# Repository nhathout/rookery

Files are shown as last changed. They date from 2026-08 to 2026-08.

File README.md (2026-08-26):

# rookery

**A desk light that tells you what your Claude Code sessions are doing.**

Green while it's working. Red when it wants you. Yellow when it's done. Glance
at the corner of your desk instead of cycling through terminal tabs.

A *rookery* is a penguin colony — which is roughly what a few concurrent agent
sessions feel like, and why one lives on the base.

```
Claude Code ──hooks──▶ localhost:8787 ──▶ daemon ──USB serial──▶ ESP32 ──▶ LEDs
```

No network. No telemetry. No cloud. Your session state never leaves the machine
it's running on.

---

## What it looks like

| LED | State | Meaning |
|---|---|---|
| 🟢 Green, slow breathe | `working` | At least one session is running |
| 🟡 Yellow, steady | `idle` | Sessions open, nothing running |
| 🔴 Red, fast pulse | `needs_you` | A session is waiting on your input |
| 🔵 Blue, very dim | `asleep` | No sessions at all |
| 🟠 Orange, slow blink | `link lost` | The daemon stopped talking — don't trust the light |
| ⚪ White, blink | `ident` | Boot self-test, or you asked it to identify itself |

Sessions are tracked individually and the most urgent one wins, so five
terminals and three worktrees still collapse into one colour.

The enclosure is a **penguin**, 91 × 55 × 117 mm, in two colours: a black
shell and a **white belly that the LEDs light from behind**. The belly is a
swappable panel — a smiley, a chick, a word, or your own — and it's the only
part you ever need to take out. Its glyph is thinned to 0.9 mm so it glows
while the rest of the panel stays opaque.

The eyes are translucent plugs that pick up spill light from inside, so they
glow faintly in whatever colour is currently showing.

---

## Bill of materials

If you own a 3D printer and a parts drawer, you probably have all of this.

| Item | Qty | Notes |
|---|---|---|
| ESP32-S3 dev board | 1 | Classic ESP32, C3 and C6 also supported |
| LEDs — red, green, blue, yellow, orange, white | 1 each | 3 mm or 5 mm through-hole |
| Resistors, 100–330 Ω | 6 | Values vary by colour — see [WIRING.md](hardware/WIRING.md) |
| M3 heat-set inserts | 6 | 4.0 mm OD, 5 mm long |
| M3 × 1/4" screws | 6 | Standard PC case screws — Micro Connectors `SCW-50M3` or any M3 × 6 mm pan head |
| **USB cable that carries data** | 1 | Not a charge-only cable |
| Zip tie, small | 1 | Strain relief on the cable |
| Black filament | ~95 g | Shell and backplate |
| White or natural filament | ~25 g | Nest, eyes, and one belly |
| *Optional:* rubber feet, 11 mm | 4 | Recesses are in the base |

Every screw in the build is the same one: **M3 × 1/4"**, six of them, into six
M3 heat-set inserts. There is nothing else to source.

Only one LED is ever lit at a time, so there's no capacitor, no level shifter
and no external power supply. The whole thing runs off the USB port that's
already carrying the serial data.

---

## Build

### 1. Flash the firmware

```bash
pip install platformio
cd firmware
pio run -e esp32s3 -t upload
pio device monitor              # expect: READY rookery 0.2.0 channels=6
```

On boot the firmware walks all six LEDs in order as a self-test. If one stays
dark, that's a wiring fault — find it now, before anything is soldered.

> **ESP32-S3 users:** a DevKitC-1 has two USB-C sockets. The default build
> routes Serial to the **native USB** port (marked `USB`). If your board has
> only one socket, that's the one. To use the `UART` bridge instead, build
> `esp32s3-uart`.

Other targets: `esp32dev`, `esp32c3`, `esp32c6`, `esp32s3-penguin` (adds the
servo), `esp32s3-neopixel` / `esp32s3-rgb` (alternate LED hardware).

### 2. Install the daemon

```bash
cd host
pip install -e .

rookery ports     # find your board (* marks likely candidates)
rookery probe     # confirm it answers
rookery test      # cycle green → yellow → red → blue
```

If `test` cycles the colours, the hardware is finished. Everything after this
is software.

**Linux:** for serial permissions, either `sudo usermod -aG dialout $USER`
(then log out and back in), or install
[`scripts/99-rookery.rules`](scripts/99-rookery.rules) for a stable
`/dev/rookery` symlink that survives replugging.

### 3. Wire it to Claude Code

```bash
rookery install-hooks
```

Merges the hook entries into `~/.claude/settings.json`, backing up the original
to `settings.json.bak` first. It only ever touches its own entries — your
existing hooks are preserved — and re-running it is idempotent.

Prefer to do it by hand? Paste [`claude/hooks.http.json`](claude/hooks.http.json)
into your settings yourself. To undo: `rookery uninstall-hooks`.

### 4. Run it

```bash
rookery run
```

Open Claude Code in another terminal and ask it something.

Autostart on Linux:

```bash
mkdir -p ~/.config/systemd/user
cp scripts/rookery.service ~/.config/systemd/user/
systemctl --user daemon-reload
systemctl --user enable --now rookery
sudo loginctl enable-linger $USER    # survive logout
```

macOS: [`scripts/com.rookery.daemon.plist`](scripts/com.rookery.daemon.plist).

### 5. Print the enclosure

**The meshes are committed — you don't need to run anything.** The `.3mf`
files in [`hardware/stl/`](hardware/stl/) are pre-arranged plates: open one in
Bambu Studio and every part arrives laid out and correctly oriented.

Five printed parts, in two colours:

| Part | Filament | What it is |
|---|---|---|
| `shell` | **Black** | The body — head, flippers, beak, belly window, eye sockets |
| `backplate` | **Black** | Rear panel; the board and the nest mount on it |
| `nest` | **White** | Holds the six LEDs and reflects their light into the belly |
| `eyes` | **White / natural** | Two plugs on a bridge |
| `belly_*` | **White / natural** | The diffuser. Pick one — this is the swappable bit. |

Plates are grouped by filament colour, so a single-extruder machine never
needs a mid-print swap:

| Plate | Filament | Parts |
|---|---|---|
| `plate1_black.3mf` | Black | `shell` |
| `plate2_black.3mf` | Black | `backplate` |
| `plate3_white.3mf` | White | `nest`, `eyes`, `belly_blank`, `belly_smiley` |
| `plate4_white.3mf` | White | `belly_chick`, `belly_text` |

Everything fits a **Bambu A1 mini** (180 × 180 × 180). If you have a 256 mm
machine, `python3 generate.py --plate 256` re-packs the set onto two plates.

3 walls, 15–20% infill, 0.2 mm layers, and **no supports on any part** —
nothing in the design overhangs past 45°, and `generate.py` measures that
rather than assuming it.

**The belly must be white or natural filament.** Its glyph is thinned to
0.9 mm while the panel around it is 2.6 mm, so light passes through the glyph
and not the frame. A dark filament gives you a dim brown oval. The `nest` is a
reflector, so print that in white too.

To change dimensions, edit the parameters at the top of
[`hardware/generate.py`](hardware/generate.py) and re-run it:

```bash
pip install trimesh manifold3d shapely numpy
cd hardware
python3 generate.py                    # rewrites stl/
python3 generate.py --insert-od 4.2    # if your inserts are fatter
python3 generate.py --led-d 3.0        # 3 mm LEDs instead of 5 mm
python3 generate.py --text "BUSY"      # your own wording
```

Every run checks itself: manifoldness after welding, plate fit, unsupported
overhang area, bridge spans, screw thread engagement, and a boolean
interference test of the assembled parts against each other and against a
solid standing in for the dev board. A bad parameter fails loudly instead of
at the printer.

### 6. Bellies

Four ship ready to print:

| Belly | What it shows |
|---|---|
| `belly_blank` | Plain glow — the whole oval lights up |
| `belly_smiley` | A smiley face — the most legible of the four |
| `belly_chick` | A pixel penguin chick, on a penguin's belly |
| `belly_text` | Reads `AFK`; change it with `--text` |

Swapping one is four screws, all on the back. The whole electrical assembly
stays on the backplate as one piece — nothing gets unsoldered.

If you design your own, keep the lit graphic **small and central**. The six
LEDs sit in a 15 mm circle about 18 mm behind a 48 × 54 mm window, so a
compact centred icon lights evenly while a graphic that reaches the rim falls
off at the edges. The text belly uses a built-in 5 × 7 bitmap font covering
A–Z, 0–9 and a few symbols, auto-scaled to fit.

Full print-and-assemble walkthrough, including the heat-set insert technique
and the order to do things in: [`hardware/stl/README.md`](hardware/stl/README.md).
Circuit and resistor values: [`hardware/WIRING.md`](hardware/WIRING.md).

---

## Usage

```bash
rookery run --brightness 90    # dimmer, for a dark room
rookery run --simulate         # log state changes, no hardware needed
rookery status                 # which sessions does it think are live?
rookery set needs_you          # force a state (stop the daemon first)
rookery print-hooks            # dump the hook JSON to stdout
```

`--simulate` is genuinely useful: you can verify the whole hook pipeline before
the hardware exists.

Six LEDs from a parts drawer will never be balanced. Trim them live over serial
with `GAIN <colour> <0-255>`, then bake the values you settle on into
`build_flags` — `env:esp32s3-tuned` in `platformio.ini` exists for that.
`WAG` triggers the penguin manually.

Full serial reference: [`docs/PROTOCOL.md`](docs/PROTOCOL.md).

---

## Troubleshooting

**Board doesn't appear in `rookery ports`** — 90% of the time it's a
charge-only USB cable. Then it's the wrong socket on an S3 (native vs UART).
Then it's a missing CP210x/CH340 driver on macOS or Windows.

**Light never changes** — run `rookery status` while a session is live. If
sessions are listed, the problem is the serial link; if not, it's the hooks.
Run `/hooks` inside Claude Code to confirm they registered.

**Light stuck on green** — the daemon died. The firmware notices after 30 s and
switches to the orange blink.

**One LED never lights during the boot self-test** — that channel is miswired,
or the LED is in backwards. The long leg is the anode and goes to the resistor.

**Blue or white looks dead or very faint** — expected, not a fault. Their
forward voltage is nearly the full 3.3 V a GPIO can supply, so they only get
about 2 mA where the others get 7. The firmware already compensates with higher
PWM duty; [`hardware/WIRING.md`](hardware/WIRING.md) has two stronger fixes.

**The belly glows brightest in the middle** — six LEDs in a 15 mm circle
lighting a 48 × 54 mm window will always fall off toward the edges. The
reflector cone and the lens boss on the back of the belly are there to fight
that, but the cheapest fix by far is to **sand the dome of each LED flat on
400-grit** until it's frosted. That turns a ~20° beam into a wide scatter and
does more than either of the other two.

**Belly is dim overall** — wrong filament. It needs white or natural PLA.
Print the `nest` in white too; it's a reflector. Also check `BRIGHT` isn't
turned down.

**Eyes barely glow** — expected. They're lit by spill light through a gap in
the crown of the reflector, so they're subtle by design and best seen in a dim
room. Printing them in natural or clear filament rather than white helps a
lot.

**Hook errors in the transcript** — the daemon isn't running. HTTP hooks report
a connection failure as a non-blocking error: visible, harmless, and it won't
interrupt your work. Switch to the command-hook variant if it bothers you; that
one exits 0 silently.

---

## Extending it

Nothing below the hook layer is Claude Code-specific. The daemon accepts any
POST to `/hook` carrying a `hook_event_name` and a `session_id`, so pointing
another tool at it is a matter of mapping that tool's events onto the four
states in [`host/rookery/state.py`](host/rookery/state.py).

The serial protocol is plain text, so you can drive the light from a shell
script, a CI webhook, or a build system without going near the daemon:

```bash
printf 'STATE needs_you\n' > /dev/rookery
```

`LED <colour> <0-255>` addresses any single LED directly if you want to invent
your own signals.

---

## Repository layout

```
firmware/         ESP32 firmware (PlatformIO)
host/rookery/     the daemon: hook endpoint, session registry, serial link
claude/           hook configuration for Claude Code
hardware/
  generate.py     parametric model generator -> STL + per-colour 3MF plates
  stl/            printable meshes, plates, and the assembly guide
  WIRING.md       circuit, resistor values, where the LEDs sit
  MOTOR.md        power budget, and adding a motor
  PRODUCTION.md   what it costs to build, and to sell
scripts/          systemd unit, launchd plist, udev rules
docs/             serial protocol reference
```

---

## Credit

The idea of a physical desk light for agent sessions isn't mine — I saw
[clawlight.dev](https://clawlight.dev), wanted one, and decided building it
would be more fun than buying it.

This is an independent implementation: its own firmware, daemon and enclosure,
six discrete LEDs instead of a diffused RGB beacon, a penguin-shaped
two-colour enclosure with a swappable backlit belly that isn't in their
product at all, and a hook-driven approach rather than session-file
watching. If you'd rather have a finished product in a nice case than a weekend
of soldering, go buy theirs.

Not affiliated with Anthropic, or with Claw Light.

## License

MIT — see [LICENSE](LICENSE).

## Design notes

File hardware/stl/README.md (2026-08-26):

# Printing and assembling the penguin

Everything in this folder is generated by [`../generate.py`](../generate.py)
and committed, so you don't need to run anything to print it.

The enclosure is a penguin, in two colours: a **black shell** and a **white
belly** that the LEDs light up from behind. Assembled it's **91 × 55 × 117 mm**
and stands on your desk.

Five printed parts, six screws, six heat-set inserts. No supports anywhere.

---

## What's in here

| File | Qty | Filament | What it is |
|---|---|---|---|
| `shell.stl` | 1 | **Black** | The body. Head, flippers, beak, belly window, eye sockets. |
| `backplate.stl` | 1 | **Black** | The rear panel. Everything electrical mounts on it. |
| `nest.stl` | 1 | **White** | Holds the six LEDs and reflects their light into the belly. |
| `eyes.stl` | 1 | **White** | Two plugs on a bridge. One part, both eyes. |
| `belly_*.stl` | 1 | **White / natural** | The diffuser. **Pick one** — this is the swappable bit. |

Four bellies ship ready to print:

| Belly | What it shows |
|---|---|
| `belly_blank` | Plain glow. The whole oval lights up evenly. |
| `belly_smiley` | A smiley face — the most legible of the four |
| `belly_chick` | A pixel penguin chick, on a penguin's belly |
| `belly_text` | Reads `AFK`; change it with `--text` |

### The plates

The `.3mf` files are pre-arranged plates. Open one in Bambu Studio and it
arrives laid out and correctly oriented — **don't rotate anything.**

| Plate | Filament | Parts | Rough time |
|---|---|---|---|
| `plate1_black.3mf` | Black | `shell` | ~5 h |
| `plate2_black.3mf` | Black | `backplate` | ~2 h |
| `plate3_white.3mf` | White | `nest`, `eyes`, `belly_blank`, `belly_smiley` | ~3 h |
| `plate4_white.3mf` | White | `belly_chick`, `belly_text` | ~2 h |

Plates are grouped by colour so a single-extruder machine never needs a
mid-print swap. Everything fits a **Bambu A1 mini** (180 × 180 × 180); the
largest part is the shell at 91 × 117 × 52 mm. If you have a 256 mm machine,
`python3 generate.py --plate 256` re-packs the whole set onto two plates.

You only need one belly to build the thing. Print the other three whenever.

### Print settings

| | |
|---|---|
| Layer height | 0.2 mm |
| Walls | 3 |
| Infill | 15% (`shell`, `backplate`), 20% (`nest`, `eyes`, `belly_*`) |
| Supports | **None.** Not on any part. |
| Brim | Not needed — every part has a large flat face on the plate |

Nothing in this design overhangs past 45°. That is checked, not assumed:
`generate.py` measures the downward-facing area of every part in its print
orientation and fails if any of it is unsupported.

> **The belly must be white or natural filament.** Its glyph is thinned to
> 0.9 mm while the panel around it is 2.6 mm, so light passes through the
> glyph and not the frame. A dark filament gives you a dim brown oval.

Printing the `nest` in white matters too — it's a reflector, and its whole
job is bouncing light. Print the `eyes` in natural/clear if you have it;
they pick up spill light from inside and glow faintly.

---

## Bill of materials

| Item | Qty | Notes |
|---|---|---|
| ESP32-S3 dev board | 1 | Classic ESP32, C3 and C6 also supported |
| LEDs — red, green, blue, yellow, orange, white | 1 each | 5 mm through-hole (or 3 mm, see `--led-d`) |
| Resistors, 100–330 Ω | 6 | Values per [`../WIRING.md`](../WIRING.md) |
| **M3 heat-set inserts** | 6 | 4.0 mm OD × 5 mm long |
| **M3 × 1/4" screws** | 6 | Standard PC case screws — e.g. Micro Connectors `SCW-50M3`. M3 × 6 mm pan or button head is the same thing. |
| Hookup wire | — | Stranded, 26–28 AWG |
| **USB cable that carries data** | 1 | Not a charge-only cable |
| Zip tie, small | 1 | Strain relief on the cable |
| *Optional:* rubber feet, 11 mm | 4 | Recesses are in the base |

**One screw type does the whole build.** All six are the same M3 × 1/4".
Four hold the backplate on, two hold the nest to the backplate.

---

## Assembly

### 0. Get the electronics working first

On a breadboard, before anything is glued or soldered short:

```bash
cd firmware && pio run -e esp32s3 -t upload
cd ../host && pip install -e . && rookery test
```

On boot the firmware walks all six LEDs in order. Any LED that stays dark is
a wiring fault, and you want to find it now rather than after it's inside a
penguin. Full circuit in [`../WIRING.md`](../WIRING.md).

### 1. Fit the six heat-set inserts

Every insert in this build goes into a face you can rest an iron on top of,
straight down. Nothing is fitted at an angle or up inside a cavity.

- **Shell — 4 inserts.** Lay the shell face down, open back up. Four round
  bosses sit against the inside wall: two low, two at shoulder height. Their
  pockets face straight up at you.
- **Backplate — 2 inserts.** Lay the backplate flat, features up. The two
  tall pillars either side of centre are the nest posts. Their pockets are
  in the top of each pillar.

Technique: set the iron to about **200 °C** for PLA, sit the insert on the
hole, and let the iron's own weight carry it in. The pockets have a 45°
lead-in chamfer, so a straight start is easy. Pushing hard squeezes molten
plastic up around the flange and leaves the insert proud. Stop when the top
is flush and let it cool before touching it.

The pockets are cut **3.85 mm** across for a **4.0 mm** insert. That 0.15 mm
is deliberate — it's the material the insert melts into and grips. If yours
measure differently, `python3 generate.py --insert-od 4.2` and reprint.

### 2. Load the LEDs into the nest

Push the six LEDs up through the holes in the flat end of the cone, from
underneath, until they seat. Keep the colour order consistent so you can
trace the loom later.

> **Worth doing:** rub the dome of each LED flat on a bit of 400-grit
> sandpaper until it's frosted. A clear 5 mm LED throws a narrow ~20° beam
> and puts a bright spot in the middle of the belly; a sanded one scatters
> across a much wider angle and lights the whole oval. It costs two minutes
> and it is the single biggest improvement you can make to how this looks.

Bend all six cathodes together into a ring underneath and solder — that's
your ground bus. Solder each anode to its resistor, then a wire from each
resistor back toward the board. **Leave the wires long.** You will regret a
tight loom the first time you open it.

Trim the legs reasonably short and lay them outward: there's 3.3 mm between
the back of the LEDs and the tallest thing on the dev board.

### 3. Screw the nest to the backplate

The nest's two ears sit on the backplate's pillars. **2 × M3 × 1/4"**, from
the cone side.

The cone is the optics. Six single-colour LEDs 18 mm behind a 48 × 54 mm
window would otherwise be a bright spot with a dim rim; the cone flares out
to the full width of the window and bounces the spill into the edges.

### 4. Fit the dev board

It drops into the pocket on four posts and clicks under four retention tabs.
Press it down until it seats. It sits **upright, USB connector pointing
down**, so the cable runs down the inside and out the back at desk level.

Solder the LED loom to the board per the channel map in
[`../WIRING.md`](../WIRING.md).

### 5. Thread the cable

Feed the USB cable in through the slot in the bottom of the backplate
**before** plugging it into the board, then zip-tie it to the two posts
either side of the slot. That way a tug on the cable pulls on the enclosure
and not on the board's USB connector.

### 6. Drop the belly into the shell

From behind, through the open back. The belly's rim is a 45° cone and the
shell's window is countersunk to match, so it self-centres and seats flush
with the outside of the shell. It cannot fall out forward.

While you're in there, press the **eyes** in from behind too. They're
tapered — narrow at the front — so they seat from the inside and can't push
through. A dab of glue on the flange if you want to be sure.

### 7. Close it up

Lower the backplate assembly into the shell. The rim on the backplate locates
it, and the nest's cone lands on the back of the belly and presses it home —
that's deliberate, it's what takes the rattle out.

**4 × M3 × 1/4"** through the back into the shell's inserts. Snug, not tight;
you're clamping a printed part.

Rubber feet in the four recesses underneath if you have them.

---

## Swapping the belly

This is the only reason you'll ever need to open it, which is why all the
screws are on the back where nobody looks.

1. Four screws out, lift the backplate assembly off (mind the LED loom).
2. Push the old belly out from behind and drop the new one in.
3. Backplate back on, four screws.

Nothing gets unsoldered. The whole electrical assembly stays on the
backplate as one piece.

### Designing your own

Start from `belly_blank` and keep the lit graphic **small and central**. The
LEDs sit in a 15 mm circle about 18 mm behind the window, so a compact
centred icon lights evenly while a graphic that reaches the rim falls off at
the edges — the cone and the lens boss fight that, but they don't beat
physics.

For text, `python3 generate.py --text "BUSY"` uses a built-in 5 × 7 bitmap
font covering A–Z, 0–9 and a few symbols, auto-scaled to fit. Four
characters or fewer light most evenly.

If you'd rather model your own from scratch, the part that matters is the
rim: a 45° cone running from a 48 × 54 mm oval at the front face out to
59 × 65 mm over 5.6 mm of depth. Everything behind that is yours.

---

## How the belly is built, and why

Front face to back:

```
   0.0 - 2.6 mm    window plate, 45-degree rim -> wedges into the shell
   2.6 - 5.6 mm    the rim carries on at 45 degrees into the flange
   5.6 - 7.6 mm    flange, straight. The nest presses on this.
```

The middle is pocketed out from the back, which leaves a 2.6 mm window with
a faceted conical boss at its centre. **The boss is the point.** It puts
extra material exactly where the LED beam is strongest and tapers away to
nothing at the edges, so the thing you see is an even glow instead of a hot
spot. The glyph is then thinned from the back to a uniform 0.9 mm floor, so
it reads bright against the field.

The visible face prints against the build plate — best surface finish, and
the thin glow floor is laid down first with no bridging at all.

---

## Regenerating

`stl/` is committed, so you can print without running anything. To change
dimensions:

```bash
pip install trimesh manifold3d shapely numpy
cd hardware
python3 generate.py                    # rewrites stl/
python3 generate.py --insert-od 4.2    # if your inserts are fatter
python3 generate.py --led-d 3.0        # 3 mm LEDs instead of 5 mm
python3 generate.py --belly-clear 0.35 # if the belly is tight
python3 generate.py --text "BUSY"      # your own wording
python3 generate.py --plate 256        # A1 / P1 / X1: two plates instead of four
python3 generate.py --leds ring        # one WS2812B ring instead of six LEDs
```

`--leds ring` reshapes the nest to seat a 12-LED WS2812B ring instead of six
through-hole LEDs: three wires instead of thirteen, and no per-unit colour
trimming. The firmware already has that backend
(`pio run -e esp32s3-neopixel`). Measure your ring and pass `--ring-od` /
`--ring-id` — 12-LED rings are commonly 37 mm across but not universally. The
recess locates the ring; hot glue or foam tape holds it. It's the change to
make if you're building more than one of these — see
[`../PRODUCTION.md`](../PRODUCTION.md).

Every run checks itself and exits non-zero if anything is wrong:

- every part is manifold **after welding at the precision the file is
  written at** — a mesh that only holds together at full float precision
  will fail in someone else's slicer
- every part fits the plate
- no part has unsupported downward-facing area
- the shell's front skin bridges the cavity: the widest span is measured
- the screw arithmetic — thread engagement and clearance past the tip
- the assembled parts are boolean-intersected against each other, and
  against a solid standing in for the dev board, so a clash is a failure
  rather than a surprise at the bench

The two numbers you're most likely to need to change are `INSERT_OD`
(measure your inserts) and `BOARD_L` / `BOARD_W` (measure your board). Both
are at the top of `generate.py`.

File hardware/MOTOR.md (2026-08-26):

# Power budget & adding a motor

> **The shipped enclosure has no servo mount.** The current design is
> deliberately static — shell, backplate, nest, eyes, belly. This document
> stays because the power arithmetic matters for any expansion, and because
> the firmware still carries optional servo support if you want to add a
> moving part of your own.

## Short answer

**No regulator, no external supply.** The light itself draws almost nothing,
and even one micro servo doing brief moves fits inside a USB port's budget with
room to spare. You need one capacitor and one rule about which pin to tap.

The rule: **take servo power from the `5V` / `VIN` pin, never from `3V3`.**

## The budget

A USB 2.0 port gives you **500 mA at 5 V** after enumeration (USB 3.0 gives
900 mA). Most desktop ports will quietly supply more, but 500 mA is the number
to design against.

| Draw | Current |
|---|---|
| ESP32 dev board (WiFi never initialised) | ~50–70 mA |
| USB-UART chip + power LED | ~15–25 mA |
| Status LEDs (one lit at a time, ≤63% duty) | ≤7 mA |
| SG90 servo, moving under light load | ~150–250 mA |
| **Total during a wag** | **~300 mA** ✅ |
| SG90 servo, **stalled** | ~650–750 mA |
| **Total if it stalls** | **~800 mA** ❌ |

So the whole design hinges on one thing: **never let the servo stall.** A
stalled servo will trip your PC's port current limit, and Windows in particular
will disable the port and pop a "USB device drew too much power" notification.

Two defences, both already in the firmware:

- Travel is limited to `SERVO_REST ± SERVO_SWING` (90° ± 28°). Set these so the
  penguin never drives into a hard stop.
- The servo is **detached** 700 ms after a move finishes. A servo that's still
  being commanded holds torque, hunts, and buzzes audibly on a quiet desk.
  Released, an SG90 draws essentially nothing.

## Why not the 3V3 pin

The `3V3` pin comes off the board's onboard linear regulator (usually an
AMS1117). Three problems:

1. A servo wants 5 V. At 3.3 V it's weak and jittery.
2. The regulator is linear, so every milliamp the servo pulls burns
   `(5 − 3.3) × I` watts as heat in a tiny SOT-223 package.
3. Servo inrush yanks the rail down. The ESP32's brownout detector trips
   around 2.6 V on the 3.3 V rail and **resets the chip**.

That third one is the single most common failure in projects like this. The
symptom is a board that reboots every time the motor moves.

## The capacitor

```
  5V (VIN) ──┬──────────────── servo red
             │
          ╔══╧══╗
          ║ 470µF║  electrolytic, 6.3 V or higher
          ╚══╤══╝   stripe = negative = GND side
             │
  GND ───────┴──────────────── servo brown/black
```

470–1000 µF across the servo's supply, physically **close to the servo**, not
next to the ESP32. It absorbs the inrush spike locally so the dip never reaches
the regulator. This is a $0.20 part that prevents the most annoying failure mode
in the build. Fit it.

## Wiring

```
  ESP32                          SG90 servo
  ─────                          ──────────
  5V / VIN ──┬───────────────── red     (power)
          [470µF]
  GND ───────┴───────────────── brown   (ground)

  GPIO17 ───────────────────── orange  (signal)   [S3; GPIO14 on classic]
```

3.3 V PWM into an SG90 works fine — no level shifter needed. If your servo's
wires are a different colour scheme, the order at the connector is almost always
**ground, power, signal** with ground on the outside edge.

Build with the servo enabled:

```bash
pio run -e esp32s3-penguin -t upload      # or esp32dev-penguin
```

That env adds `-DENABLE_SERVO` and pulls in the `ESP32Servo` library.

> **Board note:** the servo needs an **ESP32-S3 or a classic ESP32**. The S3
> has 8 LEDC channels — six LEDs plus one servo is seven, which fits. The C3
> and C6 have exactly six, and the LEDs use all of them.

**If the servo jitters or the LEDs flicker when it moves**, the LEDC peripheral
is being asked to serve two very different clock configurations (the LEDs run
at ~1 kHz / 8-bit, the servo at 50 Hz / 16-bit). The S3's four LEDC timers are
enough for both, but if your core version allocates them awkwardly, moving one
LED to a different GPIO or dropping `analogWriteFrequency` usually settles it.

## Calibration

Assemble loosely first, then in a serial monitor:

```
WAG                 # run the full attention wiggle
LED white 255       # (unrelated, but handy for checking the loom)
```

Adjust in `platformio.ini` and reflash:

- `SERVO_REST` — the neutral angle. Start at 90 and adjust.
- `SERVO_SWING` — how far it turns each way. **Reduce this if the servo grinds
  or buzzes at the extremes** — that's it hitting a mechanical stop, which is
  the stall condition you're trying to avoid.
- `SERVO_STEP_MS` — pace of the wiggle. Higher is calmer.

Get the horn position roughly right *mechanically* before fine-tuning in
software: pull the horn off the spline, centre the servo with `WAG`, and press
the horn back on pointing where you want.

You'll need to make room for it yourself — add a pocket to `build_backplate()`
in `generate.py`, or mount the servo outside the shell. There is room: the
cavity is 46 mm deep and the dev board only uses the bottom 13 mm of it. The
interference check in `generate.py` will tell you straight away if whatever
you add collides with the nest, the belly, or the board.

## What the firmware does with a servo

If you build with `-DENABLE_SERVO`, the servo wags on the **transition into
`needs_you`**, then settles. It deliberately does *not* react to `working` or
`idle` — a desk ornament that moves constantly stops being charming after about
an hour. `WAG` triggers it manually over serial.

The firmware only reacts to the state *change*, not the state value, because
the daemon re-sends the current state every 8 seconds as a heartbeat. Wagging
on the value would mean wagging forever.

## If you'd rather use a different motor

### DC motor

You cannot drive a motor from a GPIO pin. The absolute maximum is 40 mA and the
recommended continuous figure is 12 mA; a motor will pull ten to fifty times
that and take the pin (or the chip) with it.

```
  GPIO ──[ 1kΩ ]── gate/base ┐
                             │  logic-level N-MOSFET (IRLZ44N, 2N7000)
                             │  or NPN (2N2222) for small motors
              source/emitter ┴── GND

  5V ──┬──── motor ──┬── drain/collector
       │             │
       └──|◀── 1N4001 flyback diode, cathode (stripe) to 5V
```

The flyback diode is not optional. Collapsing the motor's magnetic field
generates a reverse spike that will destroy the transistor without it.

Budget-wise: a small hobby DC motor stalls at 0.5–1 A, which blows past your
USB allowance. Fine for brief pulses, not for continuous running.

### 28BYJ-48 stepper + ULN2003

Draws roughly **240 mA continuously while energised** — it fits in the budget,
but it holds that current even when stopped, gets warm, and wastes power. Drive
all four ULN2003 inputs LOW between moves to de-energise it. Uses four GPIOs.

### When you genuinely need external power

More than one servo, any continuous-duty motor, or anything above ~300 mA.

Then: a 5 V 2 A USB wall adapter powering the motor directly, with **grounds
tied together** between the adapter and the ESP32. Keep the ESP32 on the PC's
USB cable for data. Don't feed external 5 V into the board's `5V` pin while
USB is also connected unless you're sure your board has proper diode isolation
— it usually does, but "usually" isn't a thing to bet a motherboard on.

For this project, none of that applies. One servo, one USB cable, one
capacitor.

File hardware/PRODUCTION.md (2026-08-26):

# What it costs to build, and what it would take to sell

This is a parts-drawer project. It is also, with a few changes, a product.
This document is the arithmetic for both, and the honest version of what
stands between them.

Prices are indicative — check them, they move. Everything below assumes PLA,
one Bambu A1 mini, and hand assembly.

---

## Cost of one unit

| Item | Qty | 1-off | @100 |
|---|---|---|---|
| ESP32-S3 DevKitC-1 | 1 | $9.00 | $5.50 |
| LEDs, 5 mm, six colours | 6 | $0.40 | $0.15 |
| Resistors | 6 | $0.06 | $0.02 |
| M3 heat-set inserts | 6 | $0.36 | $0.12 |
| M3 × 1/4" screws | 6 | $0.12 | $0.04 |
| Hookup wire, zip tie | — | $0.25 | $0.10 |
| Rubber feet | 4 | $0.20 | $0.08 |
| USB-A/C data cable, 1 m | 1 | $2.50 | $1.10 |
| Filament — 95 g black | — | $1.90 | $1.60 |
| Filament — 25 g white | — | $0.50 | $0.42 |
| Box, insert, printed card | — | — | $2.20 |
| **Materials** | | **$15.29** | **$11.33** |

**Machine time.** About 12 hours across four plates, or roughly one unit per
A1 mini per day allowing for plate changes. That is not labour, but it is
capital and floor space: **one printer supports about 20 units a month.** Any
real volume means more printers, and printers are the cheapest thing on this
list to add.

**Labour**, which is where this actually gets expensive:

| Step | Time |
|---|---|
| Six heat-set inserts | 3 min |
| Sand six LEDs, load the nest | 4 min |
| Solder the ground bus and six resistors | 14 min |
| Solder seven wires to the board | 8 min |
| Fit board, belly, eyes, close up | 6 min |
| Flash, run `rookery test`, pack | 7 min |
| **Total** | **~42 min** |

At $25/hour that is **$17.50 a unit**, more than the materials. Add a
plausible 8% for scrap and rework and one unit lands at roughly **$30 all-in
at 100 units**.

At a 3× multiple over landed cost — which is thin for hardware once you carry
returns, support and a warranty — that is a **$89 product**. It is not a $39
product, and pretending otherwise is how hardware projects lose money
politely.

---

## The one change that matters

**Thirty of those forty-two minutes are the LED loom.** Six LEDs, six
resistors, a hand-twisted ground bus and thirteen solder joints, done by a
person, every single time. It is also where every unit-to-unit inconsistency
comes from: six LEDs from a parts drawer are never balanced, which is exactly
why `GAIN` exists.

Two ways out, in increasing order of commitment:

### 1. A WS2812B ring — the cheap fix

The firmware already supports this. `-DLED_BACKEND_NEOPIXEL` is in
`platformio.ini` today, as `env:esp32s3-neopixel`.

A 12-LED WS2812B ring module is about $1.50 and has **three wires**. No
resistors, no ground bus, no per-colour trim, no thirteen joints. Assembly
drops from 42 minutes to roughly **15**, and every unit comes out the same
colour as every other unit because the colour is now a number in firmware
rather than a property of whichever LEDs were in the bag.

| | Discrete | WS2812B ring |
|---|---|---|
| Parts | 12 | 1 |
| Solder joints | 13 | 3 |
| Assembly | 42 min | ~15 min |
| Labour @ $25/h | $17.50 | $6.25 |
| BOM change | — | +$1.35, −$0.17 |
| Colour consistency | trim each unit | identical |

That is **$10 a unit** for a $1.35 part, and it pays back on the first one.

The nest needs a ring seat instead of six bores:

```bash
python3 generate.py --leds ring --ring-od 37 --ring-id 23
```

Measure your ring — 12-LED rings are commonly 37 mm across but not
universally. The generator checks the seat against the reflector cone and the
board and fails if it doesn't fit.

The one thing you give up is the constraint that made this design what it is:
one colour at a time, at a few milliamps, off a USB port with no capacitor.
Twelve WS2812Bs at full white are 700 mA. Cap the brightness in firmware and
that is a non-issue, but it is a real change to the power story — see
[MOTOR.md](MOTOR.md).

### 2. A carrier PCB — the right fix at volume

A 40 × 40 mm two-layer board carrying six LEDs, six resistors and one header,
assembled by the fab: roughly $1.50 in boards plus $2–3 in assembly at 50
units, with a one-off setup of about $30–60. Snaps onto the nest's two screw
posts, one connector to the dev board.

It keeps the discrete-LED design exactly as it is — the low current, the one
lit at a time, the honest little indicator — and removes the same 25 minutes.
It costs more per unit than the ring and pays back somewhere around **15–25
units**, so it is the answer if you have decided the six discrete LEDs are the
product rather than an implementation detail.

Beyond a few hundred units, the dev board is the next thing to go: an ESP32-S3
module soldered onto that same PCB removes $3–4 and another connector, at the
cost of needing to care about USB, regulation and certification yourself.

---

## What ships in the box

- Assembled penguin, one belly fitted
- The other three bellies, loose — they are the demo, and they cost 40 g of
  filament and no labour
- USB data cable
- Four rubber feet
- A card with the one-line install and a link

The bellies matter more than they look like they do. They are the thing
someone shows a colleague, they cost almost nothing, and they turn "a light"
into "a light that's mine".

---

## Before you sell one

Not optional, roughly in order of how much they will hurt if skipped:

**The cable.** Half the support load on a project like this is someone using
a charge-only USB cable. Ship a known-good data cable in the box and the
problem disappears. It is the highest-value $1.10 on the BOM.

**Flash and test every unit.** `rookery test` cycles all six colours in about
ten seconds. It catches a cold joint, a backwards LED and a dead channel
before the box is sealed, which is the only place catching them is cheap.

**Regulatory.** In the US, a USB-powered device with no intentional radiator
is subject to FCC Part 15 Subpart B as an unintentional radiator; if you sell
into the EU you need CE/UKCA marking and a declaration of conformity. This is
survivable — a compliance lab will test a unit for a four-figure sum — but it
is a real cost that arrives before revenue, and it is much worse if the
firmware ever brings up WiFi. **Keep the radio off.** The current firmware
never initialises it, and that is worth defending as a design decision rather
than an accident.

**Say what it is.** This talks to Claude Code over local hooks and is not
affiliated with Anthropic. Do not imply otherwise on the box, the listing or
the site. Trademark trouble is cheap to avoid and expensive to fix.

**Firmware version in the greeting.** It is already there — `READY rookery
0.2.0 channels=6` — and it is what makes a support conversation take two
minutes instead of twenty. Bump it on every change that ships.

**Print consistency.** Colour lots vary, and the belly is a diffuser: a
"white" from a different batch changes how the finished thing looks. Buy the
white in quantity from one lot and keep a printed reference belly to compare
against.

---

## What this is worth as a product

Honestly: the enclosure is the product. The firmware and daemon are a
weekend; the thing that makes someone want one is that it is a penguin whose
belly glows, that it comes with four faces, and that swapping one takes four
screws and no soldering.

Which is also the risk. Anyone can print the enclosure — the meshes are MIT
and committed. What is actually being sold is *not having to*: the print
time, the 42 minutes of soldering, the sourcing, the tested unit, the cable
that works. Price it as assembly and support, not as a design people cannot
get, because they can.

The margin is in the assembly time. That is why the ring is the first change
to make, and why the honest answer to "can this be profitable" is: yes, at
around $89, once the LED loom stops being something a person does with their
hands.

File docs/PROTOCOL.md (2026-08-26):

# Serial protocol

115200 baud, 8N1, newline-terminated ASCII. Deliberately human-readable so you
can drive the light from a serial monitor, a shell script, or anything else —
the daemon has no privileged access.

## Host → device

| Command | Effect | Reply |
|---|---|---|
| `PING` | Liveness / identification probe | `PONG rookery 0.2.0` |
| `STATE working` | Green LED, slow breathe | `OK state working` |
| `STATE idle` | Yellow LED, steady dim | `OK state idle` |
| `STATE needs_you` | Red LED, fast pulse | `OK state needs_you` |
| `STATE asleep` | Blue LED, very dim | `OK state asleep` |
| `LED <colour> <0-255>` | Drive one LED directly | `OK led <colour>` |
| `GAIN <colour> <0-255>` | Per-channel brightness trim | `OK gain <colour> <n>` |
| `BRIGHT <0-255>` | Master brightness scale | `OK bright <n>` |
| `WAG` | Run the penguin's attention wiggle | `OK wag` |
| `IDENT` | Blink white for 2 s | `OK ident` |
| `OFF` | Same as `STATE asleep` | `OK off` |

Valid colours: `red`, `green`, `blue`, `yellow`, `orange`, `white` (or the
bare index `0`–`5`).

`GAIN` is how you balance six mismatched LEDs without reflashing. It's a
runtime trim only — set it, find values you like, then move them into
`build_flags`.

`WAG` replies `OK wag ignored` on firmware built without `-DENABLE_SERVO`, so
it's always safe to send. The penguin also wags on its own, but only on the
*transition* into `needs_you` — the daemon re-sends the current state every
8 seconds as a heartbeat, so reacting to the value rather than the change
would make it wag forever.

Unknown commands return `ERR unknown`. Malformed arguments return `ERR <cmd>`.

## Device → host

On boot: `READY rookery 0.2.0 channels=6`

Before that banner the firmware walks all six LEDs in sequence as a self-test.

Nothing else is emitted unsolicited. The daemon drains and debug-logs whatever
arrives, so extra chatter is harmless if you add your own.

## Link watchdog

If the device receives nothing for `LINK_TIMEOUT_MS` (30 s default) *after
having heard from a host at least once*, it drops to a slow orange blink: the
"link lost" state.

This exists because the alternative failure mode is worse: if the daemon dies
mid-turn while the light is green, you'd have a light on your desk confidently
telling you a session is running when nothing is. The orange blink means
"don't trust me." It's a blink rather than a steady colour so it can't be
mistaken for the steady yellow idle state at a glance.

The daemon re-sends the current state every 8 seconds, which doubles as the
heartbeat that keeps the watchdog fed.

## Testing without the daemon

```bash
# Linux/macOS
printf 'STATE needs_you\n' > /dev/ttyUSB0

# Or interactively
python3 -m serial.tools.miniterm /dev/ttyUSB0 115200
```

Then type `PING`, `STATE working`, `IDENT`, `LED orange 255`, and so on. If
this works but the daemon doesn't, the problem is in the hook wiring, not the
hardware.

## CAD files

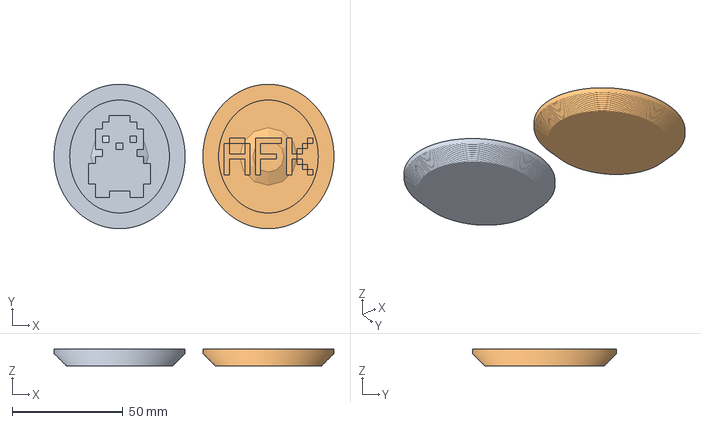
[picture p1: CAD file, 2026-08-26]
hardware/stl/plate4_white.3mf
126.4 x 65.2 x 7.60 mm
belly_chick
belly_text

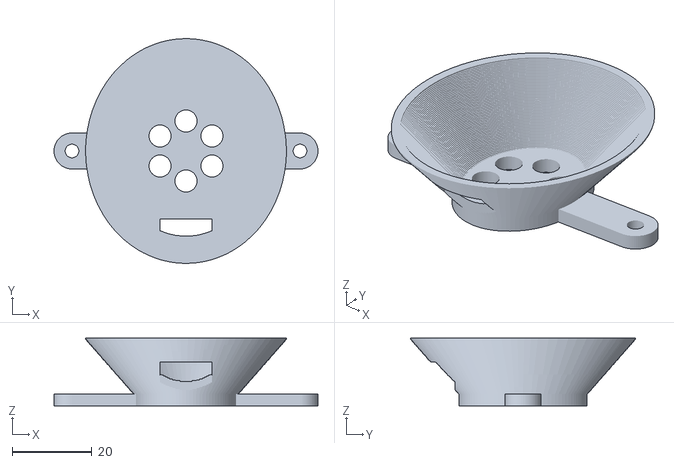
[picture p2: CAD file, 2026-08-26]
hardware/stl/nest.stl
66.0 x 56.2 x 16.9

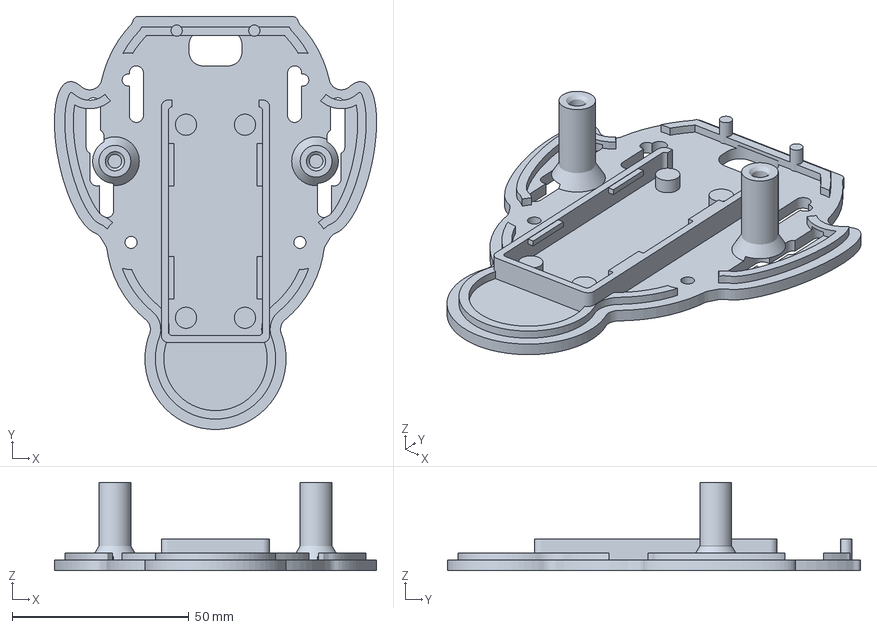
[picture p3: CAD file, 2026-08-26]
hardware/stl/plate2_black.3mf
91.3 x 117.0 x 25.0 mm

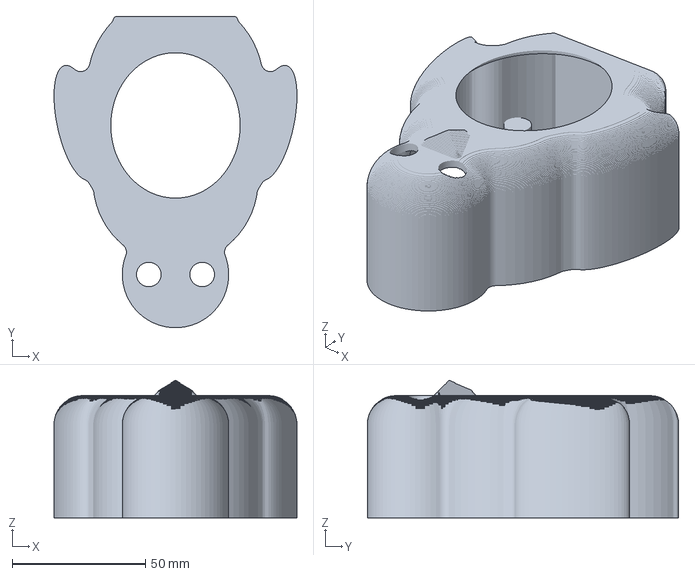
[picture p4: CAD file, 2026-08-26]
hardware/stl/plate1_black.3mf
91.3 x 117.0 x 51.8 mm

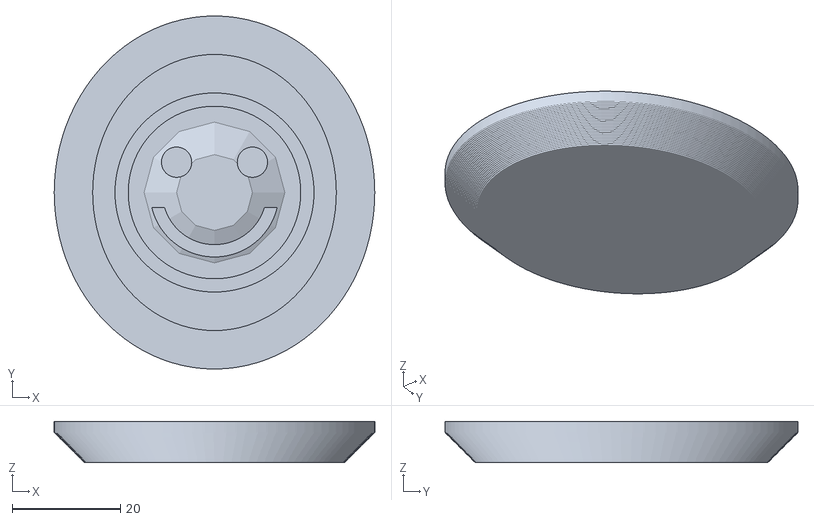
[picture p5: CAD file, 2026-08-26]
hardware/stl/belly_smiley.stl
59.2 x 65.2 x 7.60

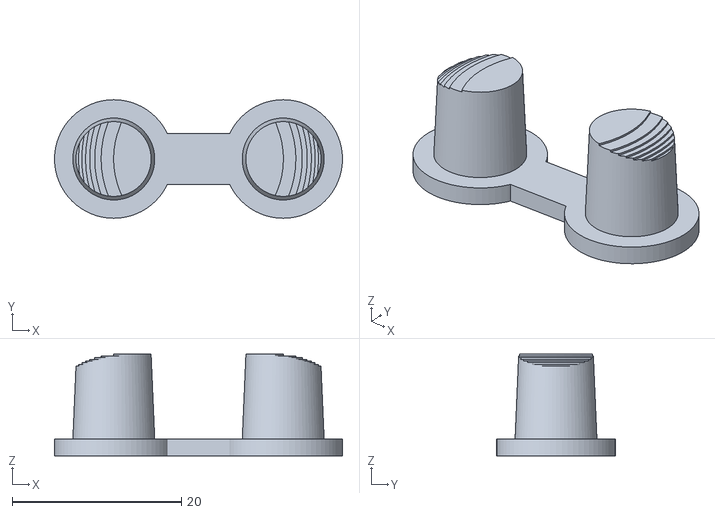
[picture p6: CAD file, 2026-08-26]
hardware/stl/eyes.stl
34.0 x 14.0 x 12.0

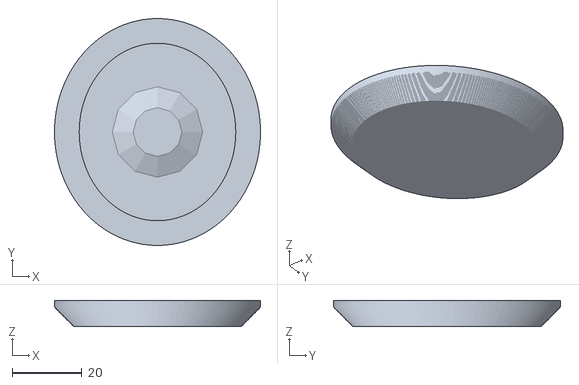
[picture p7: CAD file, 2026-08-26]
hardware/stl/belly_blank.stl
59.2 x 65.2 x 7.60

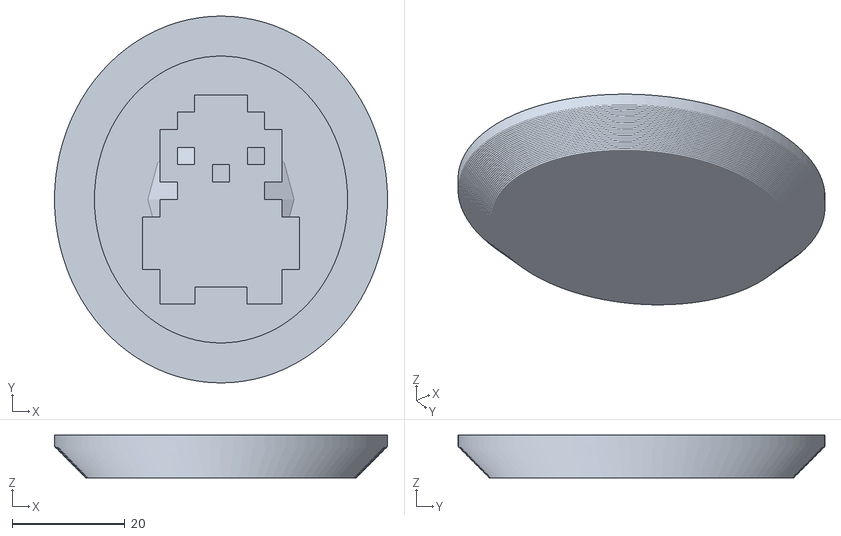
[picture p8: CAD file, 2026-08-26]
hardware/stl/belly_chick.stl
59.2 x 65.2 x 7.60

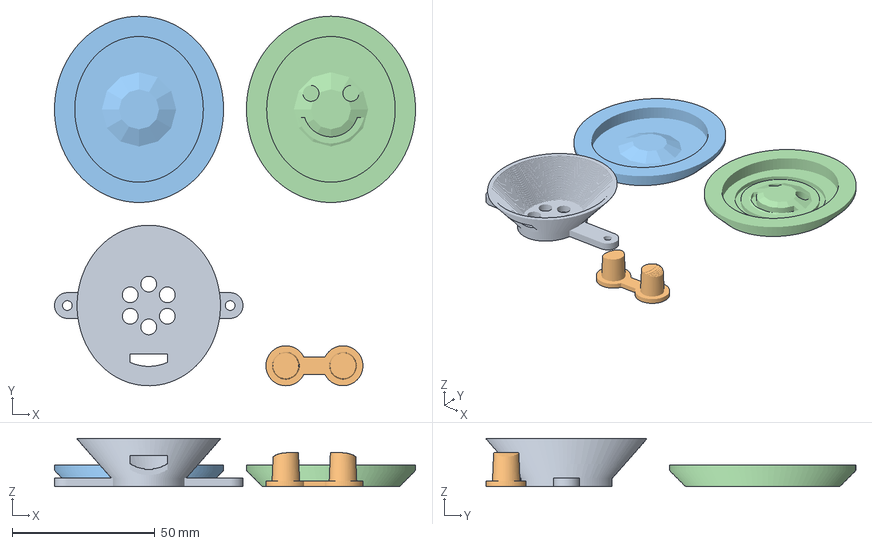
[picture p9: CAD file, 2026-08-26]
hardware/stl/plate3_white.3mf
126.4 x 129.4 x 16.9 mm
nest
eyes
belly_blank
belly_smiley

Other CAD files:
hardware/stl/backplate.stl
hardware/stl/belly_text.stl
hardware/stl/shell.stl

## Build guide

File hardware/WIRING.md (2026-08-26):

# Wiring & assembly

Six discrete single-colour LEDs, one GPIO each, sharing a common ground, behind
a backlit belly. Nothing to buy — this is a parts-drawer build.

## Channel map

| Colour | State | Behaviour | ESP32-S3 | Classic ESP32 |
|---|---|---|---|---|
| Green | working | Slow breathe | GPIO5 | GPIO26 |
| Yellow | idle | Steady, dim | GPIO7 | GPIO32 |
| Red | needs you | Fast pulse | GPIO4 | GPIO25 |
| Blue | asleep | Steady, very dim | GPIO6 | GPIO27 |
| Orange | link lost | Slow blink | GPIO15 | GPIO33 |
| White | ident / self-test | Blink on request | GPIO16 | GPIO13 |

The S3 pins are audited against everything that chip reserves: strapping pins
(0, 3, 45, 46), native USB (19, 20), SPI flash (26–32), octal PSRAM (33–37),
UART0 (43, 44), and the onboard RGB LED (38 on DevKitC-1 v1.0, 48 on v1.1).

> **Which USB socket?** An S3 DevKitC-1 has two. The default build routes
> Serial to the **native USB** port (marked `USB`). If your board has only one
> socket, that's it. To use the `UART` bridge instead, build `esp32s3-uart`.

## The circuit

Six copies of the same thing. All cathodes to one ground rail.

```
  ESP32-S3

  GPIO4  ──[ 220Ω ]──▶|── RED     ─┐
  GPIO5  ──[ 150Ω ]──▶|── GREEN   ─┤
  GPIO6  ──[ 100Ω ]──▶|── BLUE    ─┤
  GPIO7  ──[ 220Ω ]──▶|── YELLOW  ─┼── GND
  GPIO15 ──[ 220Ω ]──▶|── ORANGE  ─┤
  GPIO16 ──[ 100Ω ]──▶|── WHITE   ─┘

  ▶|  = LED, arrow points anode → cathode.
        The LONG leg is the anode (resistor / GPIO side).
        The flat spot on the rim marks the cathode.
```

## Resistor values, and why they differ

Different colours have different forward voltages, so equal resistors give
unequal brightness. Targeting roughly 7 mA:

| Colour | Typical Vf | Resistor | Result |
|---|---|---|---|
| Red | 2.0 V | 220 Ω | ~6 mA |
| Yellow | 2.1 V | 220 Ω | ~5 mA |
| Orange | 2.0 V | 220 Ω | ~6 mA |
| Green (standard) | 2.2 V | 150 Ω | ~7 mA |
| Blue | 3.0–3.2 V | 100 Ω | ~2 mA ⚠ |
| White | 3.0–3.4 V | 100 Ω | ~2 mA ⚠ |

Anything in the 100–330 Ω range works. This runs dim on purpose.

### ⚠ The blue and white problem

**Blue and white LEDs have a forward voltage of about 3.0–3.4 V, and an ESP32
GPIO only puts out 3.3 V** — less under load. There's almost no headroom to
push current through a resistor, so those two channels get ~2 mA instead of
~7 mA and look weak next to the others.

Three ways to handle it, easiest first:

1. **Do nothing.** The firmware compensates: blue and white run at higher PWM
   duty (22% and 63%) than yellow (11%), and their `GAIN` trims ship at
   maximum. Behind the diffuser belly this is usually fine, and blue only
   signals "nothing is running".
2. **Drop the resistor** to 47 Ω, or short it, on blue and white only.
   Slightly naughty, entirely normal for indicators, and PWM keeps average
   current low.
3. **Drive them from 5 V through a transistor** — see [MOTOR.md](MOTOR.md) for
   the circuit. Worth doing if you have transistors around.

If green looks dim too, you have a "pure green" InGaN LED (Vf ≈ 3.2 V) rather
than a standard one — same problem, same fixes.

### Trimming brightness without reflashing

```
GAIN blue 255
GAIN red 120
BRIGHT 200
```

Sit in a serial monitor, run `rookery test` in another terminal, and tweak
until the six colours read evenly. Then bake the values into `build_flags` —
`env:esp32s3-tuned` in `platformio.ini` exists for that.

## Current budget

Only one LED is lit at a time, always under 63% duty, so peak draw is a single
LED — call it 7 mA. Well under the 20 mA-per-pin recommendation. No capacitor,
no level shifter, no external supply.

## The printed parts and how it goes together

That's a separate document, because it's a separate job:
**[`stl/README.md`](stl/README.md)** covers what to print, in which filament,
on which plate, and in what order to bolt it together.

The short version: five printed parts, six M3 heat-set inserts, and six
M3 × 1/4" screws that are all the same screw. The LEDs live in the `nest`, a
white reflector cone that bolts to the backplate and lights the penguin's
belly from behind.

## Where the LEDs sit

```
        back                                              front
      y = 0                y = 22..25                   y = 46
        |                       |                          |
   [ backplate ]           [ nest plate ]            [ belly ]
        |    \__ post __/        | 6 LEDs                 |
   [ dev board ]                 \____ reflector cone ____/
                                        flares to 48 mm
```

Six LEDs in a 15 mm circle, 18 mm behind a 48 × 54 mm window, one lit at a
time. Three things stop that reading as a bright spot with a dim rim:

1. **The cone.** It flares from the LED plate out to the full width of the
   window, in white filament, and bounces the spill into the edges.
2. **The lens boss** on the back of the belly: a faceted cone of extra
   material right where the beam is strongest, tapering to nothing at the
   rim. Thicker plastic in the middle, thinner at the edge, so what comes
   out the front is even.
3. **Sanding the LEDs.** Rub the dome of each one flat on 400-grit until
   it's frosted. A clear 5 mm LED throws a ~20° beam; a frosted one
   scatters far wider. Two minutes, no cost, and it makes more difference
   than either of the other two.

There's a deliberate gap in the crown of the cone. Spill light goes up
through the body and reaches the two translucent eye plugs, which glow
faintly in whatever colour is currently showing. It's subtle — best in a
dim room — and it's a bonus rather than a feature. Printing the eyes in
natural or clear filament rather than white makes it noticeably stronger.

## Bill of materials

| Item | Qty | Notes |
|---|---|---|
| ESP32-S3 dev board | 1 | Classic ESP32, C3 and C6 also supported |
| LEDs — red, green, blue, yellow, orange, white | 1 each | 5 mm (or 3 mm, see `--led-d`) |
| Resistors, 100–330 Ω | 6 | Values per the table above |
| M3 heat-set inserts | 6 | 4.0 mm OD × 5 mm long |
| M3 × 1/4" screws | 6 | PC case screws — e.g. Micro Connectors `SCW-50M3`. M3 × 6 mm pan head is the same thing. |
| Hookup wire | — | Stranded, 26–28 AWG |
| **USB cable that carries data** | 1 | Not a charge-only cable |
| Zip tie, small | 1 | Strain relief on the cable |
| Black filament | ~95 g | Shell and backplate |
| White or natural filament | ~25 g | Nest, eyes, and one belly |
| *Optional:* rubber feet, 11 mm | 4 | Recesses are in the base |

The thing that still trips people up: **the cable**. Plenty of USB cables in
a drawer are power-only with no data lines. If the board never shows up in
`rookery ports`, swap the cable before debugging anything else.

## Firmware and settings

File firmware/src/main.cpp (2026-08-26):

// rookery firmware
// A USB-serial status light for coding-agent sessions.
//
// Default build drives SIX discrete single-colour LEDs, one per state:
//
//   green   working     slow breathe
//   yellow  idle        steady, dim
//   red     needs you   fast pulse
//   blue    asleep      steady, very dim
//   orange  link lost   slow blink  (the host daemon stopped talking)
//   white   ident       blink on request / boot self-test
//
// Protocol (newline-terminated ASCII, 115200 8N1) -- see docs/PROTOCOL.md
//   ->  PING                 <-  PONG rookery <fw>
//   ->  STATE working        <-  OK state working
//   ->  BRIGHT 120           <-  OK bright 120
//   ->  GAIN blue 255        <-  OK gain blue 255
//   ->  IDENT                <-  OK ident
//   ->  OFF                  <-  OK off
//
// Alternate backends (see platformio.ini):
//   -DLED_BACKEND_NEOPIXEL    addressable WS2812B/SK6812 ring
//   -DLED_BACKEND_RGB         single 4-pin common-cathode RGB LED

#include <Arduino.h>

#define FW_VERSION "0.2.0"
#define DEVICE_NAME "rookery"

#if !defined(LED_BACKEND_NEOPIXEL) && !defined(LED_BACKEND_RGB)
#define LED_BACKEND_DISCRETE 1
#endif

#ifndef SERIAL_BAUD
#define SERIAL_BAUD 115200
#endif

// How long without a host message before we assume the link is dead.
#ifndef LINK_TIMEOUT_MS
#define LINK_TIMEOUT_MS 30000UL
#endif

// ---------------------------------------------------------------------------
// State model
// ---------------------------------------------------------------------------

enum State : uint8_t {
  ST_ASLEEP = 0,   // no live sessions
  ST_IDLE,         // sessions open, nothing running
  ST_WORKING,      // at least one session is running
  ST_NEEDS_YOU,    // a session wants your input
  ST_LINK_LOST,    // host daemon stopped talking to us
  ST_MANUAL        // host drove the channels directly
};

static State g_state = ST_ASLEEP;
static uint8_t g_brightness = 160;      // 0..255 master scale
static unsigned long g_lastHostMs = 0;
static bool g_everHeardHost = false;
static unsigned long g_identUntilMs = 0;

// ---------------------------------------------------------------------------
// Channels
// ---------------------------------------------------------------------------

enum Ch : uint8_t {
  CH_RED = 0, CH_GREEN, CH_BLUE, CH_YELLOW, CH_ORANGE, CH_WHITE, CH_COUNT
};

static const char *kChNames[CH_COUNT] = {
  "red", "green", "blue", "yellow", "orange", "white"
};

#if defined(LED_BACKEND_DISCRETE)

// Pins. Defaults are for a classic ESP32 DevKitC and deliberately avoid the
// strapping pins (0, 2, 12, 15), the flash pins (6-11) and the input-only
// pins (34-39). Override any of them in platformio.ini.
#ifndef PIN_RED
#define PIN_RED 25
#endif
#ifndef PIN_GREEN
#define PIN_GREEN 26
#endif
#ifndef PIN_BLUE
#define PIN_BLUE 27
#endif
#ifndef PIN_YELLOW
#define PIN_YELLOW 32
#endif
#ifndef PIN_ORANGE
#define PIN_ORANGE 33
#endif
#ifndef PIN_WHITE
#define PIN_WHITE 13
#endif

static const uint8_t kPins[CH_COUNT] = {
  PIN_RED, PIN_GREEN, PIN_BLUE, PIN_YELLOW, PIN_ORANGE, PIN_WHITE
};

// Per-channel trim, 0..255.
//
// Six LEDs from a parts bin will never be balanced. Red and yellow read much
// brighter to the eye than blue at the same current, and blue/white are
// current-starved on a 3.3 V pin to begin with (their forward voltage is
// close to the supply). So: knock the bright ones down, leave the dim ones
// wide open. Trim to taste at runtime with `GAIN <colour> <0-255>`, then bake
// the values you like into build_flags.
#ifndef GAIN_RED
#define GAIN_RED 150
#endif
#ifndef GAIN_GREEN
#define GAIN_GREEN 200
#endif
#ifndef GAIN_BLUE
#define GAIN_BLUE 255
#endif
#ifndef GAIN_YELLOW
#define GAIN_YELLOW 175
#endif
#ifndef GAIN_ORANGE
#define GAIN_ORANGE 175
#endif
#ifndef GAIN_WHITE
#define GAIN_WHITE 255
#endif

static uint8_t g_gain[CH_COUNT] = {
  GAIN_RED, GAIN_GREEN, GAIN_BLUE, GAIN_YELLOW, GAIN_ORANGE, GAIN_WHITE
};

#elif defined(LED_BACKEND_NEOPIXEL)
#include <Adafruit_NeoPixel.h>
#ifndef LED_PIN
#define LED_PIN 5
#endif
#ifndef LED_COUNT
#define LED_COUNT 12
#endif
static Adafruit_NeoPixel strip(LED_COUNT, LED_PIN, NEO_GRB + NEO_KHZ800);

#else  // LED_BACKEND_RGB
#ifndef PIN_R
#define PIN_R 25
#endif
#ifndef PIN_G
#define PIN_G 26
#endif
#ifndef PIN_B
#define PIN_B 27
#endif
#ifndef RGB_COMMON_ANODE
#define RGB_COMMON_ANODE 0
#endif
#endif

// ---------------------------------------------------------------------------
// Optional servo: the penguin turns to look at you when a session needs input
// ---------------------------------------------------------------------------
// Build with -DENABLE_SERVO. Needs a classic ESP32 or an S3: the C3 and C6
// only have six LEDC channels total and the six LEDs already use all of them.

#ifdef ENABLE_SERVO
#include <ESP32Servo.h>

#ifndef PIN_SERVO
#define PIN_SERVO 14
#endif
#ifndef SERVO_REST
#define SERVO_REST 90        // degrees, penguin facing forward
#endif
#ifndef SERVO_SWING
#define SERVO_SWING 28       // how far it turns each way
#endif
#ifndef SERVO_STEP_MS
#define SERVO_STEP_MS 260    // time per swing
#endif
#ifndef SERVO_SETTLE_MS
#define SERVO_SETTLE_MS 700  // hold power this long after a move, then release
#endif

static Servo g_servo;
static bool g_servoAttached = false;
static unsigned long g_detachAt = 0;
static int8_t g_wagLeft = 0;
static unsigned long g_wagNext = 0;

static void servoGo(int deg, unsigned long now) {
  if (!g_servoAttached) {
    g_servo.setPeriodHertz(50);
    g_servo.attach(PIN_SERVO, 500, 2400);
    g_servoAttached = true;
  }
  g_servo.write(constrain(deg, 0, 180));
  g_detachAt = now + SERVO_SETTLE_MS;
}

static void startWag() {
  g_wagLeft = 7;   // six swings, then a settle back to rest
  g_wagNext = 0;   // fire on the next tick
}

static void servoTick(unsigned long now) {
  if (g_wagLeft > 0 && now >= g_wagNext) {
    g_wagLeft--;
    int deg = (g_wagLeft == 0)
                ? SERVO_REST
                : ((g_wagLeft % 2) ? SERVO_REST - SERVO_SWING
                                   : SERVO_REST + SERVO_SWING);
    servoGo(deg, now);
    g_wagNext = now + SERVO_STEP_MS;
  }

  // Detaching stops the PWM once the move is done. Two reasons: a servo that
  // is still being commanded holds torque, hunts, and buzzes audibly on a
  // quiet desk; and it keeps drawing current we'd rather not pull from a USB
  // port. Released, an SG90 draws essentially nothing.
  if (g_servoAttached && g_detachAt && now > g_detachAt && g_wagLeft == 0) {
    g_servo.detach();
    g_servoAttached = false;
    g_detachAt = 0;
  }
}

#define SERVO_TICK(now) servoTick(now)
#define SERVO_ON_NEEDS_YOU() startWag()
#else
#define SERVO_TICK(now) ((void)0)
#define SERVO_ON_NEEDS_YOU() ((void)0)
#endif

// ---------------------------------------------------------------------------
// Helpers
// ---------------------------------------------------------------------------

static inline uint8_t scale8(uint8_t v, uint8_t s) {
  return (uint8_t)(((uint16_t)v * (uint16_t)s) / 255);
}

// Cheap gamma. LED brightness is linear in current but the eye is not, so a
// linear PWM ramp looks like it slams to full and then crawls. Squaring gets
// most of the way to a perceptually even fade for one line of code.
static inline uint8_t gamma8(uint8_t v) {
  return (uint8_t)(((uint16_t)v * (uint16_t)v) / 255);
}

static inline uint8_t clamp255(uint16_t v) {
  return v > 255 ? 255 : (uint8_t)v;
}

// Triangle wave 0..255 over `periodMs`.
static uint8_t triWave(unsigned long now, unsigned long periodMs) {
  unsigned long t = now % periodMs;
  unsigned long half = periodMs / 2;
  if (t < half) return (uint8_t)((t * 255UL) / half);
  return (uint8_t)(((periodMs - t) * 255UL) / half);
}

// ---------------------------------------------------------------------------
// Output
// ---------------------------------------------------------------------------

// One brightness per logical colour channel, before gamma/gain/master.
struct Lamp {
  uint8_t v[CH_COUNT];
};

static Lamp lampOff() {
  Lamp l;
  for (uint8_t i = 0; i < CH_COUNT; i++) l.v[i] = 0;
  return l;
}

static void writeLamp(const Lamp &l) {
#if defined(LED_BACKEND_DISCRETE)
  for (uint8_t i = 0; i < CH_COUNT; i++) {
    uint8_t v = gamma8(l.v[i]);
    v = scale8(v, g_gain[i]);
    v = scale8(v, g_brightness);
    analogWrite(kPins[i], v);
  }
#else
  // Fold the six logical channels down to one RGB colour so the alternate
  // backends can share the same animation code.
  uint16_t r = l.v[CH_RED] + l.v[CH_YELLOW] + l.v[CH_ORANGE] + l.v[CH_WHITE];
  uint16_t g = l.v[CH_GREEN] + l.v[CH_YELLOW]
             + (uint16_t)(l.v[CH_ORANGE] * 65 / 255) + l.v[CH_WHITE];
  uint16_t b = l.v[CH_BLUE] + l.v[CH_WHITE];
  uint8_t R = scale8(clamp255(r), g_brightness);
  uint8_t G = scale8(clamp255(g), g_brightness);
  uint8_t B = scale8(clamp255(b), g_brightness);
  R = gamma8(R); G = gamma8(G); B = gamma8(B);
#if defined(LED_BACKEND_NEOPIXEL)
  uint32_t packed = strip.Color(R, G, B);
  for (uint16_t i = 0; i < LED_COUNT; i++) strip.setPixelColor(i, packed);
  strip.show();
#else
#if RGB_COMMON_ANODE
  R = 255 - R; G = 255 - G; B = 255 - B;
#endif
  analogWrite(PIN_R, R);
  analogWrite(PIN_G, G);
  analogWrite(PIN_B, B);
#endif
#endif
}

// ---------------------------------------------------------------------------
// Animation
// ---------------------------------------------------------------------------

static Lamp g_manual = lampOff();

// Animation levels, 0..255, before gamma/gain/master brightness.
//
// These are NOT balanced by eye across colours on purpose -- they compensate
// for physics. Blue and white sit at 24-40% duty while yellow sits at 11%,
// because a blue LED on a 3.3 V pin only gets a couple of milliamps (its
// forward voltage is nearly the supply) while yellow gets a comfortable
// seven. Equal duty would make blue invisible. If your blue is still too
// faint, raise LVL_ASLEEP or see WIRING.md for the transistor fix.
#ifndef LVL_WORK_MIN
#define LVL_WORK_MIN 115
#endif
#ifndef LVL_WORK_SPAN
#define LVL_WORK_SPAN 140
#endif
#ifndef LVL_NEEDS_MIN
#define LVL_NEEDS_MIN 100
#endif
#ifndef LVL_NEEDS_SPAN
#define LVL_NEEDS_SPAN 155
#endif
#ifndef LVL_IDLE
#define LVL_IDLE 130
#endif
#ifndef LVL_LOST
#define LVL_LOST 210
#endif
#ifndef LVL_ASLEEP
#define LVL_ASLEEP 150
#endif

static Lamp renderState(unsigned long now) {
  Lamp l = lampOff();

  // IDENT overrides everything: white blink so you can find the device.
  if (now < g_identUntilMs) {
    l.v[CH_WHITE] = (((now / 120) % 2) == 0) ? 255 : 0;
    return l;
  }

  switch (g_state) {
    case ST_MANUAL:
      return g_manual;

    case ST_WORKING:
      // Calm breathe.
      l.v[CH_GREEN] = LVL_WORK_MIN + scale8(LVL_WORK_SPAN, triWave(now, 2600));
      break;

    case ST_NEEDS_YOU:
      // Faster and more insistent.
      l.v[CH_RED] = LVL_NEEDS_MIN + scale8(LVL_NEEDS_SPAN, triWave(now, 900));
      break;

    case ST_IDLE:
      l.v[CH_YELLOW] = LVL_IDLE;
      break;

    case ST_LINK_LOST:
      // Short blink on a long cycle: present, obviously not a normal state,
      // and easy to tell apart from steady yellow at a glance.
      l.v[CH_ORANGE] = ((now % 4000) < 260) ? LVL_LOST : 0;
      break;

    case ST_ASLEEP:
    default:
      l.v[CH_BLUE] = LVL_ASLEEP;
      break;
  }
  return l;
}

// ---------------------------------------------------------------------------
// Command parsing
// ---------------------------------------------------------------------------

static bool parseState(const char *name, State &out) {
  if (!strcasecmp(name, "working")) { out = ST_WORKING; return true; }
  if (!strcasecmp(name, "idle")) { out = ST_IDLE; return true; }
  if (!strcasecmp(name, "needs_you") || !strcasecmp(name, "needs")) {
    out = ST_NEEDS_YOU; return true;
  }
  if (!strcasecmp(name, "asleep") || !strcasecmp(name, "off")) {
    out = ST_ASLEEP; return true;
  }
  return false;
}

static int parseChannel(const char *name) {
  for (uint8_t i = 0; i < CH_COUNT; i++) {
    if (!strcasecmp(name, kChNames[i])) return i;
  }
  // Also accept a bare index.
  if (name[0] >= '0' && name[0] <= '5' && name[1] == '\0') return name[0] - '0';
  return -1;
}

static void handleLine(char *line) {
  size_t n = strlen(line);
  while (n > 0 && (line[n - 1] == '\r' || line[n - 1] == ' ' ||
                   line[n - 1] == '\t')) {
    line[--n] = '\0';
  }
  if (n == 0) return;

  g_lastHostMs = millis();
  g_everHeardHost = true;
  if (g_state == ST_LINK_LOST) g_state = ST_ASLEEP;

  char *cmd = strtok(line, " ");
  if (!cmd) return;

  if (!strcasecmp(cmd, "PING")) {
    Serial.printf("PONG %s %s\n", DEVICE_NAME, FW_VERSION);
    return;
  }

  if (!strcasecmp(cmd, "STATE")) {
    char *arg = strtok(nullptr, " ");
    State s;
    if (arg && parseState(arg, s)) {
      // Only on the TRANSITION into needs_you. The daemon re-sends the
      // current state every 8 s as a heartbeat, so reacting to the value
      // rather than the change would make the penguin wag forever.
      if (s == ST_NEEDS_YOU && g_state != ST_NEEDS_YOU) SERVO_ON_NEEDS_YOU();
      g_state = s;
      Serial.printf("OK state %s\n", arg);
    } else {
      Serial.println("ERR state");
    }
    return;
  }

  if (!strcasecmp(cmd, "LED")) {
    // LED <colour> <0-255> -- light one channel directly.
    char *cs = strtok(nullptr, " ");
    char *vs = strtok(nullptr, " ");
    int ch = cs ? parseChannel(cs) : -1;
    if (ch >= 0 && vs) {
      g_manual = lampOff();
      g_manual.v[ch] = (uint8_t)constrain(atoi(vs), 0, 255);
      g_state = ST_MANUAL;
      Serial.printf("OK led %s\n", kChNames[ch]);
    } else {
      Serial.println("ERR led");
    }
    return;
  }

  if (!strcasecmp(cmd, "GAIN")) {
    char *cs = strtok(nullptr, " ");
    char *vs = strtok(nullptr, " ");
    int ch = cs ? parseChannel(cs) : -1;
    if (ch >= 0 && vs) {
#if defined(LED_BACKEND_DISCRETE)
      g_gain[ch] = (uint8_t)constrain(atoi(vs), 0, 255);
      Serial.printf("OK gain %s %u\n", kChNames[ch], g_gain[ch]);
#else
      Serial.println("OK gain ignored");
#endif
    } else {
      Serial.println("ERR gain");
    }
    return;
  }

  if (!strcasecmp(cmd, "BRIGHT")) {
    char *arg = strtok(nullptr, " ");
    if (arg) {
      g_brightness = (uint8_t)constrain(atoi(arg), 0, 255);
      Serial.printf("OK bright %u\n", g_brightness);
    } else {
      Serial.println("ERR bright");
    }
    return;
  }

  if (!strcasecmp(cmd, "WAG")) {
#ifdef ENABLE_SERVO
    startWag();
    Serial.println("OK wag");
#else
    Serial.println("OK wag ignored");
#endif
    return;
  }

  if (!strcasecmp(cmd, "IDENT")) {
    g_identUntilMs = millis() + 2000;
    Serial.println("OK ident");
    return;
  }

  if (!strcasecmp(cmd, "OFF")) {
    g_state = ST_ASLEEP;
    Serial.println("OK off");
    return;
  }

  Serial.println("ERR unknown");
}

static void pumpSerial() {
  static char buf[96];
  static size_t len = 0;

  while (Serial.available() > 0) {
    int ch = Serial.read();
    if (ch < 0) break;
    if (ch == '\n') {
      buf[len] = '\0';
      handleLine(buf);
      len = 0;
    } else if (len < sizeof(buf) - 1) {
      buf[len++] = (char)ch;
    } else {
      len = 0;  // overlong line: discard rather than run a truncated command
    }
  }
}

// ---------------------------------------------------------------------------

void setup() {
  Serial.begin(SERIAL_BAUD);

#if defined(LED_BACKEND_DISCRETE)
  for (uint8_t i = 0; i < CH_COUNT; i++) {
    pinMode(kPins[i], OUTPUT);
    analogWrite(kPins[i], 0);
  }
#elif defined(LED_BACKEND_NEOPIXEL)
  strip.begin();
  strip.setBrightness(255);
  strip.clear();
  strip.show();
#else
  pinMode(PIN_R, OUTPUT);
  pinMode(PIN_G, OUTPUT);
  pinMode(PIN_B, OUTPUT);
#endif

  // Boot self-test: walk every channel in order. If one never lights, you
  // know which LED or solder joint to look at before you write any software.
  for (uint8_t i = 0; i < CH_COUNT; i++) {
    Lamp l = lampOff();
    l.v[i] = 255;
    writeLamp(l);
    delay(180);
  }
  writeLamp(lampOff());

  g_lastHostMs = millis();
  Serial.printf("READY %s %s channels=%d\n", DEVICE_NAME, FW_VERSION, CH_COUNT);
}

void loop() {
  pumpSerial();

  unsigned long now = millis();

  // Link watchdog. Only engages once we've actually heard from a host, so a
  // board sitting on the bench without a daemon just stays asleep.
  if (g_everHeardHost && g_state != ST_LINK_LOST &&
      (now - g_lastHostMs) > LINK_TIMEOUT_MS) {
    g_state = ST_LINK_LOST;
  }

  SERVO_TICK(now);
  writeLamp(renderState(now));
  delay(16);  // ~60 Hz
}

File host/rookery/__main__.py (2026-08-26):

"""rookery command line interface."""

from __future__ import annotations

import argparse
import json
import logging
import sys
import time
import urllib.request
from pathlib import Path

from . import install_hooks as hooks_mod
from .daemon import Daemon
from .serial_link import SerialLink, describe_ports, probe
from .state import ASLEEP, IDLE, NEEDS_YOU, WORKING


def _setup_logging(verbose: bool) -> None:
    logging.basicConfig(
        level=logging.DEBUG if verbose else logging.INFO,
        format="%(asctime)s %(levelname)-7s %(name)s: %(message)s",
        datefmt="%H:%M:%S",
    )


def cmd_ports(args) -> int:
    print("Serial ports (* = likely an ESP32):")
    print(describe_ports())
    return 0


def cmd_probe(args) -> int:
    if args.port:
        ok = probe(args.port, args.baud)
        print(f"{args.port}: {'beacon found' if ok else 'no response'}")
        return 0 if ok else 1
    from .serial_link import autodetect

    found = autodetect(args.baud)
    if found:
        print(f"beacon found on {found}")
        return 0
    print("no beacon found; is it plugged in and flashed?")
    return 1


def cmd_run(args) -> int:
    _setup_logging(args.verbose)
    daemon = Daemon(
        port=args.port,
        baud=args.baud,
        http_host=args.http_host,
        http_port=args.http_port,
        brightness=args.brightness,
        simulate=args.simulate,
    )
    return daemon.run()


def cmd_test(args) -> int:
    """Cycle the light through every state so you can check the wiring."""
    _setup_logging(args.verbose)
    link = SerialLink(args.port, args.baud)
    link.start()
    if args.brightness is not None:
        link.send(f"BRIGHT {args.brightness}")
    try:
        for state in (WORKING, IDLE, NEEDS_YOU, ASLEEP):
            print(f"  -> {state}")
            if not link.send(f"STATE {state}"):
                print("  !! write failed -- check the port")
                return 1
            time.sleep(args.dwell)
    finally:
        link.stop()
    return 0


def cmd_set(args) -> int:
    link = SerialLink(args.port, args.baud)
    link.start()
    try:
        ok = link.send(f"STATE {args.state}")
        return 0 if ok else 1
    finally:
        link.stop()


def cmd_status(args) -> int:
    url = f"http://{args.http_host}:{args.http_port}/status"
    try:
        with urllib.request.urlopen(url, timeout=2) as r:
            print(json.dumps(json.loads(r.read()), indent=2))
        return 0
    except Exception as exc:
        print(f"could not reach the daemon at {url}: {exc}", file=sys.stderr)
        return 1


def cmd_install_hooks(args) -> int:
    path = Path(args.settings).expanduser()
    url = f"http://{args.http_host}:{args.http_port}/hook"
    print(hooks_mod.install(path, url))
    print("Restart any running Claude Code sessions to pick up the change.")
    return 0


def cmd_uninstall_hooks(args) -> int:
    path = Path(args.settings).expanduser()
    print(hooks_mod.uninstall(path))
    return 0


def cmd_print_hooks(args) -> int:
    url = f"http://{args.http_host}:{args.http_port}/hook"
    print(json.dumps({"hooks": hooks_mod.build_hooks(url)}, indent=2))
    return 0


def build_parser() -> argparse.ArgumentParser:
    p = argparse.ArgumentParser(
        prog="rookery",
        description="Drive a USB status light from your coding-agent sessions.",
    )
    p.add_argument("-v", "--verbose", action="store_true")
    sub = p.add_subparsers(dest="command", required=True)

    def add_serial(sp):
        sp.add_argument("--port", help="serial device (default: autodetect)")
        sp.add_argument("--baud", type=int, default=115200)

    def add_http(sp):
        sp.add_argument("--http-host", default="127.0.0.1")
        sp.add_argument("--http-port", type=int, default=8787)

    sp = sub.add_parser("run", help="run the daemon")
    add_serial(sp)
    add_http(sp)
    sp.add_argument("--brightness", type=int, help="0-255 master brightness")
    sp.add_argument(
        "--simulate",
        action="store_true",
        help="log state changes instead of driving hardware",
    )
    sp.set_defaults(func=cmd_run)

    sp = sub.add_parser("ports", help="list serial ports")
    sp.set_defaults(func=cmd_ports)

    sp = sub.add_parser("probe", help="find a beacon on the bus")
    add_serial(sp)
    sp.set_defaults(func=cmd_probe)

    sp = sub.add_parser("test", help="cycle through every state")
    add_serial(sp)
    sp.add_argument("--dwell", type=float, default=2.5)
    sp.add_argument("--brightness", type=int)
    sp.set_defaults(func=cmd_test)

    sp = sub.add_parser("set", help="force one state (daemon must be stopped)")
    add_serial(sp)
    sp.add_argument("state", choices=[WORKING, IDLE, NEEDS_YOU, ASLEEP])
    sp.set_defaults(func=cmd_set)

    sp = sub.add_parser("status", help="show tracked sessions")
    add_http(sp)
    sp.set_defaults(func=cmd_status)

    sp = sub.add_parser("install-hooks", help="add hooks to Claude Code")
    add_http(sp)
    sp.add_argument("--settings", default=str(hooks_mod.DEFAULT_SETTINGS))
    sp.set_defaults(func=cmd_install_hooks)

    sp = sub.add_parser("uninstall-hooks", help="remove our hooks again")
    sp.add_argument("--settings", default=str(hooks_mod.DEFAULT_SETTINGS))
    sp.set_defaults(func=cmd_uninstall_hooks)

    sp = sub.add_parser("print-hooks", help="dump the hook JSON to stdout")
    add_http(sp)
    sp.set_defaults(func=cmd_print_hooks)

    return p


def main(argv=None) -> int:
    args = build_parser().parse_args(argv)
    return args.func(args)


if __name__ == "__main__":
    sys.exit(main())

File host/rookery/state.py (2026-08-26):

"""Session registry and state aggregation.

Every Claude Code session is tracked independently. The beacon shows the most
urgent state across all of them: needs_you beats working beats idle.
"""

from __future__ import annotations

import threading
import time
from dataclasses import dataclass, field

# Logical states, in ascending order of urgency.
ASLEEP = "asleep"
IDLE = "idle"
WORKING = "working"
NEEDS_YOU = "needs_you"

PRIORITY = {IDLE: 1, WORKING: 2, NEEDS_YOU: 3}

# Which Claude Code hook event maps to which session state.
# None means "forget this session entirely".
EVENT_STATE = {
    "SessionStart": IDLE,
    "UserPromptSubmit": WORKING,
    "PreToolUse": WORKING,
    "PostToolUse": WORKING,
    "PostToolUseFailure": WORKING,
    "PostToolBatch": WORKING,
    "Notification": NEEDS_YOU,
    "StopFailure": NEEDS_YOU,
    "Stop": IDLE,
    "SessionEnd": None,
}

# Notification is a broad event. Only these subtypes actually mean
# "a human needs to look at this"; anything else is treated as working.
ATTENTION_NOTIFICATIONS = {
    "permission_prompt",
    "idle_prompt",
    "agent_needs_input",
    "elicitation_dialog",
    "elicitation_url_dialog",
}


@dataclass
class Session:
    state: str
    updated: float = field(default_factory=time.time)
    cwd: str = ""


class Registry:
    """Thread-safe map of session_id -> Session."""

    def __init__(self, stale_after: float = 8 * 3600):
        self._sessions: dict[str, Session] = {}
        # Reentrant: snapshot() calls aggregate() while already holding it.
        self._lock = threading.RLock()
        self._stale_after = stale_after

    # -- ingestion ---------------------------------------------------------

    def apply_event(self, payload: dict) -> str | None:
        """Feed one hook payload in. Returns the new session state, or None
        if the event was ignored or ended the session."""
        event = payload.get("hook_event_name")
        session_id = payload.get("session_id")
        if not event or not session_id:
            return None

        if event not in EVENT_STATE:
            return None

        new_state = EVENT_STATE[event]

        if event == "Notification":
            # Claude Code puts the subtype in different places depending on
            # version; check the obvious ones and fall back to "attention".
            subtype = (
                payload.get("notification_type")
                or payload.get("type")
                or ""
            )
            if subtype and subtype not in ATTENTION_NOTIFICATIONS:
                return None

        with self._lock:
            if new_state is None:
                self._sessions.pop(session_id, None)
                return None

            existing = self._sessions.get(session_id)
            if existing is None:
                self._sessions[session_id] = Session(
                    state=new_state, cwd=payload.get("cwd", "")
                )
            else:
                existing.state = new_state
                existing.updated = time.time()
                if payload.get("cwd"):
                    existing.cwd = payload["cwd"]
            return new_state

    def forget(self, session_id: str) -> None:
        with self._lock:
            self._sessions.pop(session_id, None)

    def clear(self) -> None:
        with self._lock:
            self._sessions.clear()

    # -- readout -----------------------------------------------------------

    def sweep(self) -> None:
        """Drop sessions we haven't heard from in a long time. SessionEnd is
        usually delivered, but a hard kill -9 on a terminal will skip it."""
        cutoff = time.time() - self._stale_after
        with self._lock:
            dead = [k for k, v in self._sessions.items() if v.updated < cutoff]
            for k in dead:
                del self._sessions[k]

    def aggregate(self) -> str:
        with self._lock:
            if not self._sessions:
                return ASLEEP
            return max(
                (s.state for s in self._sessions.values()),
                key=lambda s: PRIORITY.get(s, 0),
            )

    def snapshot(self) -> dict:
        with self._lock:
            return {
                "aggregate": self.aggregate() if self._sessions else ASLEEP,
                "count": len(self._sessions),
                "sessions": {
                    sid: {
                        "state": s.state,
                        "age": round(time.time() - s.updated, 1),
                        "cwd": s.cwd,
                    }
                    for sid, s in self._sessions.items()
                },
            }

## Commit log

2026-08-26 Initial commit: rookery status light
    [case.stl, holder.stl, lid.stl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]
2026-08-26 hardware: rebuild the enclosure as a two-tone penguin
    The old case worked but three things about it did not survive contact with
    an actual screw and an actual heat-set insert:
    * the lid counterbore was 6.00 mm across for a DIN 7985 M3 pan head whose
    max diameter is 6.00 mm, so the head does not go in at all
    * that counterbore was 2.2 mm deep against a 2.28-2.52 mm head, so even
    filed down the head stood proud
    * the insert pocket was cut at the insert's own nominal 4.0 mm OD, leaving
    no material for the iron to melt into. The insert spins the first time a
    screw is tightened
    All three are fixed by not having a counterbore: the screws now go in from
    the back where nothin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
    [backplate.stl, belly_blank.stl, belly_chick.stl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]
2026-08-26 hardware: make the 3MF plates byte-reproducible
    A 3MF is a zip, and zip entries carry the wall clock. Re-running the
    generator rewrote all four plate files with identical geometry inside,
    which made every regeneration look like a change.
    [plate1_black.3mf, plate2_black.3mf, plate3_white.3mf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]
